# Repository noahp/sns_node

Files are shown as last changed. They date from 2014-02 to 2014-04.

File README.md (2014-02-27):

sns_node
=====
Wireless sensor node system, comprised of 3(+1) components:  
* Sensor Node (2.4GHz low power radios)
* Network Monitor (network interface)
* Internet Bridge (user interface)
* (Repeater, optional, range extender)  
block diagram  

parts
=====
node micro
-----
[mouser part MKL02Z8](http://www.mouser.com/ProductDetail/Freescale-Semiconductor/MKL02Z8VFG4/?qs=sGAEpiMZZMttKWgNLnZcJr8OOhcQcoey)  
[datasheet](http://cache.freescale.com/files/32bit/doc/data_sheet/KL02P32M48SF0.pdf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)  
[ref manual](http://cache.freescale.com/files/32bit/doc/ref_manual/KL02P32M48SF0RM.pdf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)

network monitor micro
-----
[mouser part MKL26Z256](http://www.mouser.com/ProductDetail/Freescale-Semiconductor/MKL26Z256VLH4/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)  
[datasheet](http://cache.freescale.com/files/microcontrollers/doc/data_sheet/KL26P121M48SF4.pdf)  
[ref manual](http://cache.freescale.com/files/microcontrollers/doc/ref_manual/KL26P121M48SF4RM.pdf)

power
-----
[low power lps](http://www.mouser.com/ProductDetail/Microchip-Technology/MCP1640T-I-CHY/?qs=sGAEpiMZZMsnDbBzJh6VGDDeXjwaXPWp)  
[inductor 4.7uH](http://www.mouser.com/ProductDetail/Sumida/CDRH4D18CNP-100PC/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)  
[battery holder AA](http://www.mouser.com/ProductDetail/Eagle-Plastic-Devices/12BH311A-GR/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)  
[battery holder AAA](http://www.mouser.com/ProductDetail/Eagle-Plastic-Devices/12BH412-GR/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)  
[ldo 3.3v](http://www.mouser.com/ProductDetail/Skyworks-Solutions-Inc/AAT3220IGY-33-T1/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), [datasheet](http://www.mouser.com/ds/2/472/202250A-258357.pdf)  
usb connector
-----
[micro b](http://www.mouser.com/ProductDetail/FCI/10118192-0001LF/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)
temp/humidity sensor
-----
[silabs](http://www.mouser.com/ProductDetail/Silicon-Labs/Si7020-A10-GM/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), [datasheet](http://www.silabs.com/Support%20Documents/TechnicalDocs/Si7020.pdf)

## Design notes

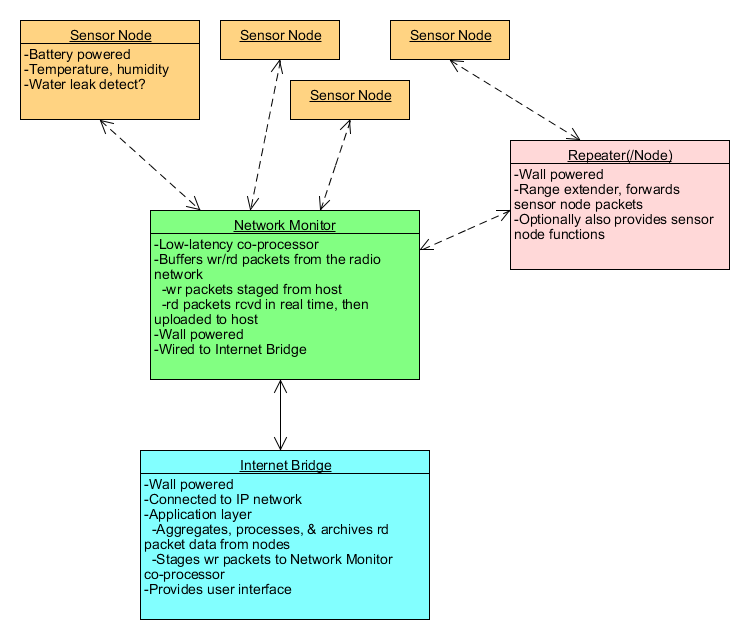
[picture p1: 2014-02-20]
doc/sns_node.png

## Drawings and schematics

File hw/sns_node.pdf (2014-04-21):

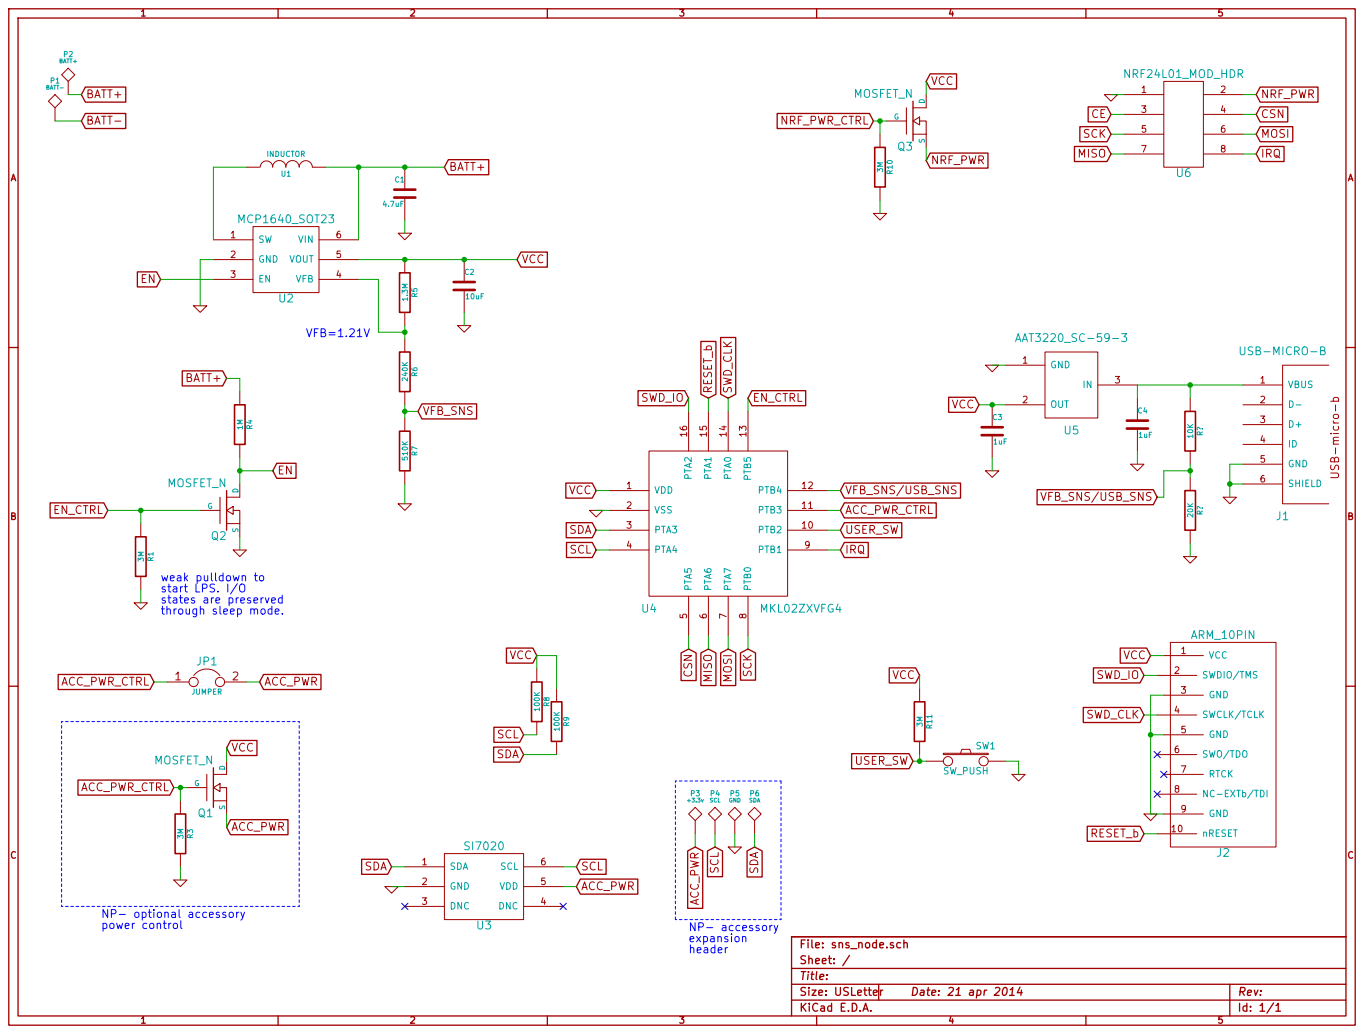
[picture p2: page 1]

8 PTB1 9 PTB2 10 PTB3 11 PTB4 12 PTB5 13 PTA0 14 PTA1 15 PTA2 16 U4 MKL02ZXVFG4 BATT+ BATT- SW 1 GND 2 EN 3 VFB 4 VOUT 5 VIN 6 U2 MCP1640_SOT23

through sleep mode. 3MR1 NP- optional accessory

Id: 1/1 Title: File: sns_node.sch
Sheet: /

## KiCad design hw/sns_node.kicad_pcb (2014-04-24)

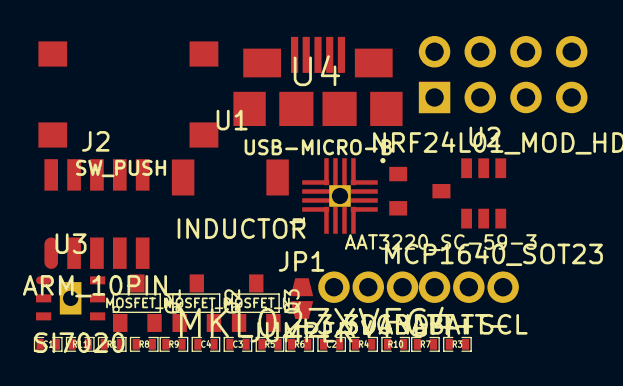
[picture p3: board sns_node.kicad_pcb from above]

Board: 2 copper layers, 33 parts (0 on the bottom side), 22 nets, no tracks yet.

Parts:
C1: 4.7uF; SM0402
C2: 10uF; SM0402
C3, C4: 1uF; SM0402
J1: USB-MICRO-B; usb_micro_b_smt
J2: ARM_10PIN; ARM_10_PIN_SMT
JP1: JUMPER; jmp_small
P1: BATT-; TEST_0.100
P2: BATT+; TEST_0.100
P3: +3.3v; TEST_0.100
P4: SCL; TEST_0.100
P5: GND; TEST_0.100
P6: SDA; TEST_0.100
Q1, Q3: MOSFET_N; SOT23
Q2: MOSFET_P; SOT23
R1, R3, R10, R11: 3M; SM0402
R4: 1M; SM0402
R5: 1.3M; SM0402
R6: 240K; SM0402
R7: 510K; SM0402
R8, R9: 100K; SM0402
SW1: SW_PUSH; spst_pushbutton_smd
U1: INDUCTOR; CDRH4D18C_inductor
U2: MCP1640_SOT23; MCP1640
U3: SI7020; si7020_dfn6
U4: MKL02ZXVFG4; MKL02_QFN16
U5: AAT3220_SC-59-3; sc59
U6: NRF24L01_MOD_HDR; nrf24_8pin

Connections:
ACC_PWR: JP1.2, P3.1, U3.5
ACC_PWR_CTRL: JP1.1, R3.1, U4.11
BATT+: C1.1, P2.1, R4.1, U1.2, U2.6
CSN: U4.5, U6.4
EN: R4.2, U2.3
EN_CTRL: R1.1, U4.13
GND: C1.2, C2.2, C3.2, C4.2, J1.5, J1.6, J2.3, J2.5, J2.9, P5.1, R1.2, R3.2, R7.2, R10.2, SW1.2, U2.2, U3.2, U4.2, U5.1, U6.1
IRQ: U4.9, U6.8
MISO: U4.6, U6.7
MOSI: U4.7, U6.6
unnamed: C4.1, J1.1, U5.3
unnamed: R5.2, R6.1, U2.4
unnamed: U1.1, U2.1
RESET_b: J2.10, U4.15
SCK: U4.8, U6.5
SCL: P4.1, R8.2, U3.6, U4.4
SDA: P6.1, R9.2, U3.1, U4.3
SWD_CLK: J2.4, U4.14
SWD_IO: J2.2, U4.16
SWITCH/VBUS_SNS: R11.2, SW1.1, U4.10
VCC: C2.1, C3.1, J2.1, R5.1, R8.1, R9.1, R11.1, U2.5, U4.1, U5.2
VFB_SNS: R6.2, R7.1, U4.12

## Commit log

2014-02-18 - add kicadlib
2014-02-18 - add project files
    [sns_node.sch]
2014-02-18 - add power supply
    [sns_node.sch]
2014-02-18 - add pfet to control en signal
    [sns_node.sch]
2014-02-20 - add header for 24l01
    [sns_node.sch]
2014-02-20 - add nrf pwr control
    [sns_node.sch]
2014-02-20 - add voltage sns circuit, connected to on chip comparator.
    [sns_node.sch]
2014-02-20 - schematic done, add net list
    [sns_node.sch]
2014-02-20 - add usb voltage supply + ldo
    [sns_node.sch]
2014-02-23 - possible circuit to provide momentary turn on when battery is connected
    [sns_node.sch]
2014-02-25 - add header for connecting i2c daughter boards - add acc_pwr fet
    [sns_node.sch]
2014-02-27 - remove power-on circuit, pullup OK because IO keeps state during micro sleep.
    [sns_node.sch]
2014-03-08 - new kicadlib, associations.
    [sns_node.sch]
2014-03-18 - associate modules with footprints.
    [sns_node.kicad_pcb]
2014-04-21 - change vbus sns to share vfb_sns pin. add pdf.
    [sns_node.sch]
2014-04-24 - update schematic and place comps
    [sns_node.kicad_pcb, sns_node.sch]
